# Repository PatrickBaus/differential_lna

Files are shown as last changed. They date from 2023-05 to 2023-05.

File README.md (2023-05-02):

Low Noise Differential Amplifier
===================

This repository contains the schematics and mechanical files for a low noise diffrential amplifier based on the Linear Technologies [AN-159](https://www.analog.com/media/en/technical-documentation/app-notes/an-159.pdf).

Key Features:
 * Bandwidth (-3 dB): 10 Hz - 1.5 MHz
 * Gain: 80 dB (10.000)
 * Noise floor $500\text{ pV}/\sqrt{\text{Hz}}$
 * Note: Requires a very low source impedance! Less than 10 Ohm.

The design was done using [KiCAD 7](https://www.kicad.org/).

Mechanical Design
------------------------------
The PCB should be housed in a mild steel box (e.g. cookie jar).

About
-----

The root folder contains the KiCAD files, while the gerber files can be found in the [/gerber](gerber/) folder, the bill of materials in the [/bom](bom/) folder.

Related Repositories
--------------------

See the following repositories for more information

KiCAD footprints: https://github.com/PatrickBaus/footprints.pretty

KiCAD 3D models: https://github.com/PatrickBaus/footprints.3dshapes

KiCAD schematic libraries: https://github.com/PatrickBaus/KiCad-libraries

License
-------

This work is released under the Cern OHL v.1.2
See www.ohwr.org/licenses/cern-ohl/v1.2 or the included LICENSE file for more information.

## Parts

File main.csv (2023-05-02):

Source: | /home/maat/Documents/Uni/Physik/Phd/Low Noise Amp/KiCAD/main.sch
Date: | 2017-03-31T00:32:30 CEST
Tool: | Eeschema (2017-01-18 revision 2eb840b2e)-master
Component Count: | 177
Ref | Qnty | Value | Cmp name | Footprint | Description | Vendor
C1, C27, C67, C72, C77, | 5 | 1u | FCA1206A105M-H3 | Capacitors_SMD:C_1206 | Unpolarized capacitor | Cornell Dubilier | 15 | x
C2, C3, C68, C69, C73, C74, C78, C79, | 8 | 33p | 12065A330JAT2A | Capacitors_SMD:C_1206 | Unpolarized capacitor | AVX | 20 | x
C4, C5, C28, C29, C30, C31, C36, C37, C70, C71, C75, C76, C80, C81, | 14 | 1u | MKS2C041001F00KC00 | Capacitors_ThroughHole:C_Rect_L7.2mm_W5.5mm_P5.00mm_FKS2_FKP2_MKS2_MKP2 | Unpolarized capacitor | WIMA | 30 | x
C6, C8, C10, C12, C14, C16, C18, C20, C22, C24, C7, C9, C11, C13, C15, C17, C19, C21, C23, C25, | 20 | 150u | T491X157K020AT | Capacitors_Tantalum_SMD:CP_Tantalum_Case-X_EIA-7343-43_Reflow | Polarised capacitor | Kemet | 50 | x
C26, | 1 | 2.2n | FKP2D012201D00JSSD | Capacitors_ThroughHole:C_Rect_L7.2mm_W4.5mm_P5.00mm_FKS2_FKP2_MKS2_MKP2 | Unpolarized capacitor | WIMA
C32, C33, | 2 | 330u | TPSE337M010R0100 | Capacitors_Tantalum_SMD:CP_Tantalum_Case-D_EIA-7343-31_Reflow | Polarised capacitor | AVX | 5 | x
C34, C35, | 2 | 4.7u | MKS2B044701K00KC00 | Capacitors_ThroughHole:C_Rect_L7.2mm_W8.5mm_P5.00mm_FKP2_FKP2_MKS2_MKP2 | Unpolarized capacitor | WIMA | 5 | x
C38, | 1 | 120p | 12065A121JAT2A | Capacitors_SMD:C_1206 | Unpolarized capacitor | AVX | 5 | x
C39, | 1 | 1.2n | 12065A122JAT2A | Capacitors_SMD:C_1206 | Unpolarized capacitor | AVX | 5 | x
C40, | 1 | 100p | 12065A101JAT2A | Capacitors_SMD:C_1206 | Unpolarized capacitor | AVX | 5 | x
C41, | 1 | 1n | 12065A102JAT2A | Capacitors_SMD:C_1206 | Unpolarized capacitor | AVX | 5 | x
C42, | 1 | 150p | 12065A151JAT2A | Capacitors_SMD:C_1206 | Unpolarized capacitor | AVX | 5 | x
C43, | 1 | 1.5n | 12065A152JAT2A | Capacitors_SMD:C_1206 | Unpolarized capacitor | AVX | 5 | x
C44, | 1 | 22p | 12065A220JAT2A | Capacitors_SMD:C_1206 | Unpolarized capacitor | AVX | 5 | x
C45, | 1 | 220p | 12065A221JAT2A | Capacitors_SMD:C_1206 | Unpolarized capacitor | AVX | 5 | x
C57, C64, C58, C65, C59, C66, C52, C48, C51, C47, C50, C46, C63, C55, C62, C54, C61, C53, C60, C56, C49, | 21 | 100u | GRM32ER61A107ME20K | Capacitors_SMD:C_1210 | Unpolarized capacitor | Murata | 50 | x
C82, | 2 | 180u | 25SEPF180M | Capacitors_ThroughHole:CP_Radial_D8.0mm_P3.50mm | Polarised capacitor | Panasonic | 5 | x
FID1, FID2, FID3, | 3 | FIDUCIAL |  | Fiducials:Fiducial_1mm_Dia_2.54mm_Outer_CopperTop | Fiducial for pick and place maschines
J3, J4, J5, J6, | 4 | CONN_01X01 |  | Wire_Pads:SolderWirePad_single_2-5mmDrill | Connector, single row, 01x01, pin header
P2, P1, P3, J1, J2, | 5 | SMA |  | Connect:SMA_THT_Jack_Straight
Q1, Q2, Q3, Q4, | 4 | THAT300 |  | Housings_SOIC:SOIC-14_3.9x8.7mm_Pitch1.27mm | NPN Array |  | 8 | x
R1, R2, R45, R46, R47, R48, R59, R60, | 8 | 100 | MFR-25FBF52-100R | Resistors_ThroughHole:R_Axial_DIN0207_L6.3mm_D2.5mm_P10.16mm_Horizontal | Resistor | Yageo | 20 | x
R3, R4, R35, R36, R49, R50, R61, R62, | 8 | 49.9 | MFR-25FBF52-49R9 | Resistors_ThroughHole:R_Axial_DIN0207_L6.3mm_D2.5mm_P10.16mm_Horizontal | Resistor | Yageo | 20 | x
R5, R7, R6, R10, R37, R39, R38, R42, R51, R53, R52, R56, R63, R65, R64, R68, | 16 | 4.02k | MFR-25FBF52-4K02 | Resistors_ThroughHole:R_Axial_DIN0207_L6.3mm_D2.5mm_P10.16mm_Horizontal | Resistor | Yageo | 35 | x
R9, R8, R41, R40, R55, R54, R67, R66, | 8 | 1.3k | MFR-25FRF52-1K3 | Resistors_ThroughHole:R_Axial_DIN0207_L6.3mm_D2.5mm_P10.16mm_Horizontal | Resistor | Yageo | 20 | x
R11, R12, R43, R44, R57, R58, R69, R70, | 8 | 1k | CPF0805B1K0E | Resistors_SMD:R_0805 | Resistor | TE Connectivity | 20 | x
R13, R18, R19, | 3 | 1k | MFR-25FBF52-1K | Resistors_ThroughHole:R_Axial_DIN0207_L6.3mm_D2.5mm_P10.16mm_Horizontal | Resistor | Yageo | 5+3 | x
R14, R15, | 2 | 249 | SFR2500002490FR500 | Resistors_ThroughHole:R_Axial_DIN0207_L6.3mm_D2.5mm_P10.16mm_Horizontal | Resistor | Vishay | 5 | x
R16, R17, | 2 | 475 | MFR-25FRF52-475R | Resistors_ThroughHole:R_Axial_DIN0207_L6.3mm_D2.5mm_P10.16mm_Horizontal | Resistor | Yageo | 5 | x
R20, | 1 | 1.13k | CRCW12061K13FKEA | Resistors_SMD:R_1206 | Resistor | Vishay | 10 | x
R21, | 1 | 10.2k | CRCW120610K2FKEA | Resistors_SMD:R_1206 | Resistor | Vishay | 10 | x
R22, | 1 | 100 | CRCW1206100RFKEA | Resistors_SMD:R_1206 | Resistor | Vishay | 5 | x
R23, | 1 | 1.5k | CRCW12061K50FKEA | Resistors_SMD:R_1206 | Resistor | Vishay | 5 | x
R24, R25, | 2 | 1.69k | CRCW12061K69FKEA | Resistors_SMD:R_1206 | Resistor | Vishay | 5 | x
R26, R27, | 2 | 1.24k | CRCW12061K24FKEA | Resistors_SMD:R_1206 | Resistor | Vishay | 5 | x
R28, R29, | 2 | 4.02k | CRCW12064K02FKEA | Resistors_SMD:R_1206 | Resistor | Vishay | 5 | x
R30, R31, | 2 | 2.15k | CRCW12062K15FKEA | Resistors_SMD:R_1206 | Resistor | Vishay | 5 | x
R33, R32, R34, | 3 | 49.9 | CRCW120649R9FKEA | Resistors_SMD:R_1206 | Resistor | Vishay | 10 | x
RV1, | 1 | 1k | 3296Y-1-102 | Potentiometers:Potentiometer_Trimmer_Bourns_3296Y | Potentionmeter | Bourns | 3 | x
U1, U2, U5, U6, U7, | 5 | LT1994 |  | Housings_SSOP:MSOP-8_3x3mm_Pitch0.65mm | Low Noise, Low Distortion Fully Differential Input/Output Amplifier/Driver |  | 12 | x
U3, | 1 | LT6232 |  | Housings_SSOP:SSOP-16_3.9x4.9mm_Pitch0.635mm | 215MHz, Rail-to-Rail Output, 1.1nV/√Hz, 3.5mA Op Amp |  | 3 | x
U4, | 1 | LT1365 |  | Housings_SOIC:SOIC-16_3.9x9.9mm_Pitch1.27mm |  |  | 2 | x

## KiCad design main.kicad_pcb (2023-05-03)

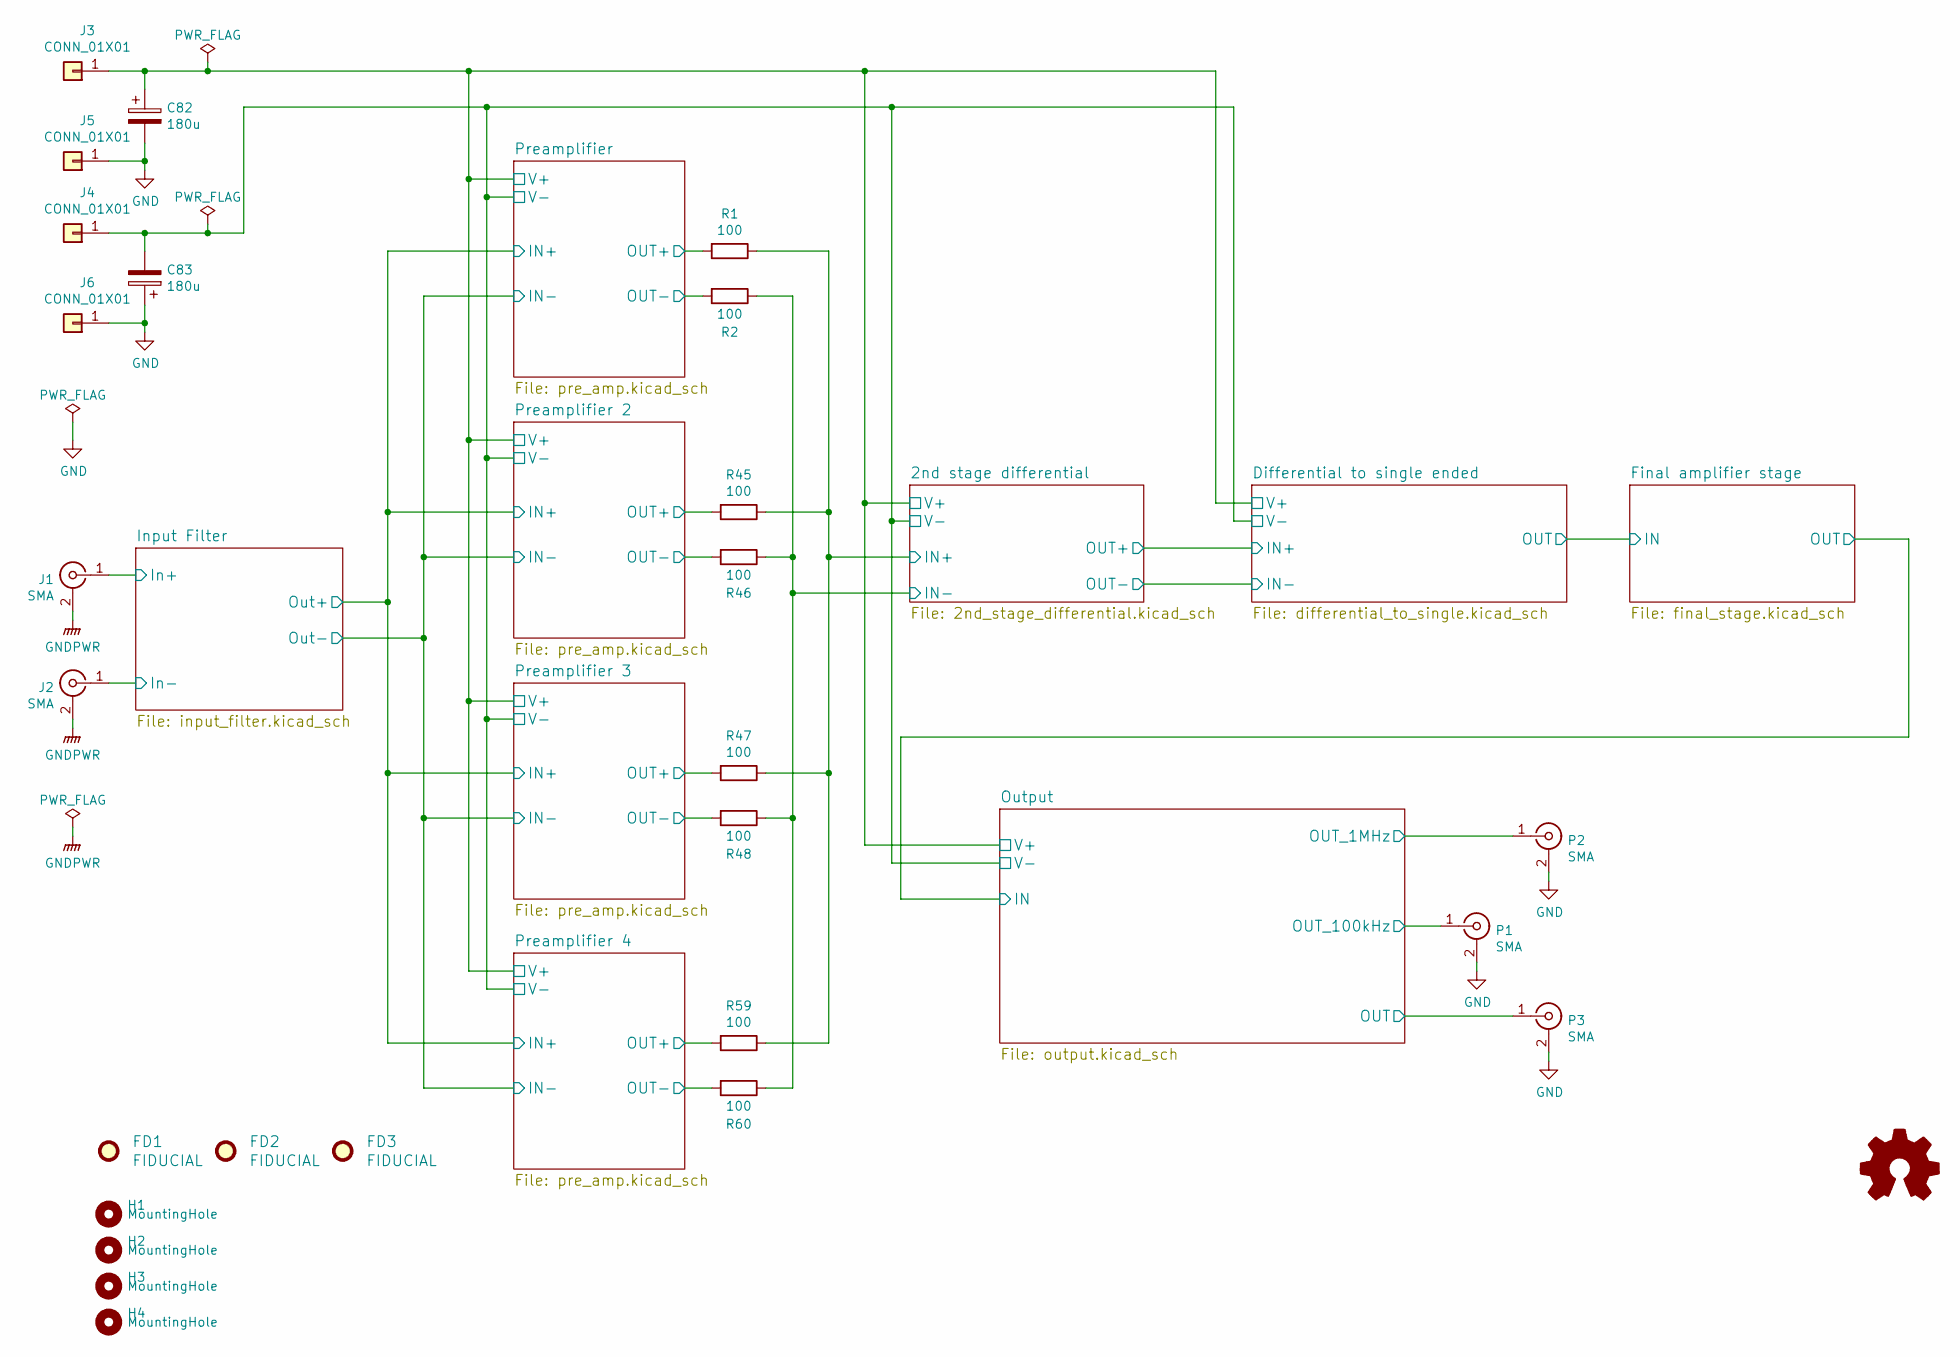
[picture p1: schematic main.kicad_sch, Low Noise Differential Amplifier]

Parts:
C82, C83: 180u; CP_Radial_D8.0mm_P3.50mm
FD1, FD2, FD3: FIDUCIAL; Fiducial_1mm_Mask2mm
H1, H2, H3, H4: MountingHole; MountingHole_3.2mm_M3_DIN965
J1, J2: SMA; SMA_Amphenol_901-144_Vertical
J3, J4, J5, J6: CONN_01X01; TestPoint_Loop_D3.80mm_Drill2.5mm
P1, P2, P3: SMA; SMA_Amphenol_901-144_Vertical
R1, R2, R45, R46, R47, R48, R59, R60: 100; R_Axial_DIN0207_L6.3mm_D2.5mm_P10.16mm_Horizontal

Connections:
/2nd stage differential/IN+: R1.1, R45.1, R47.1, R59.1; also elsewhere on the board
/2nd stage differential/IN-: R2.1, R46.1, R48.1, R60.1; also elsewhere on the board
/2nd stage differential/V+: C82.1, J3.1; also elsewhere on the board
/2nd stage differential/V-: C83.2, J4.1; also elsewhere on the board
/Input Filter/In+: J1.1 (In); also elsewhere on the board
/Input Filter/In-: J2.1 (In); also elsewhere on the board
/Output/OUT: P3.1 (In); also elsewhere on the board
/Output/OUT_1MHz: P2.1 (In); also elsewhere on the board
/Output/OUT_100kHz: P1.1 (In); also elsewhere on the board
/Preamplifier 2/OUT+: R45.2; also elsewhere on the board
/Preamplifier 2/OUT-: R46.2; also elsewhere on the board
/Preamplifier 3/OUT+: R47.2; also elsewhere on the board
/Preamplifier 3/OUT-: R48.2; also elsewhere on the board
/Preamplifier 4/OUT+: R59.2; also elsewhere on the board
/Preamplifier 4/OUT-: R60.2; also elsewhere on the board
/Preamplifier/OUT+: R1.2; also elsewhere on the board
/Preamplifier/OUT-: R2.2; also elsewhere on the board
GND: C82.2, C83.1, J5.1, J6.1, P1.2 (Ext), P2.2 (Ext), P3.2 (Ext); also elsewhere on the board
GNDPWR: J1.2 (Ext), J2.2 (Ext)

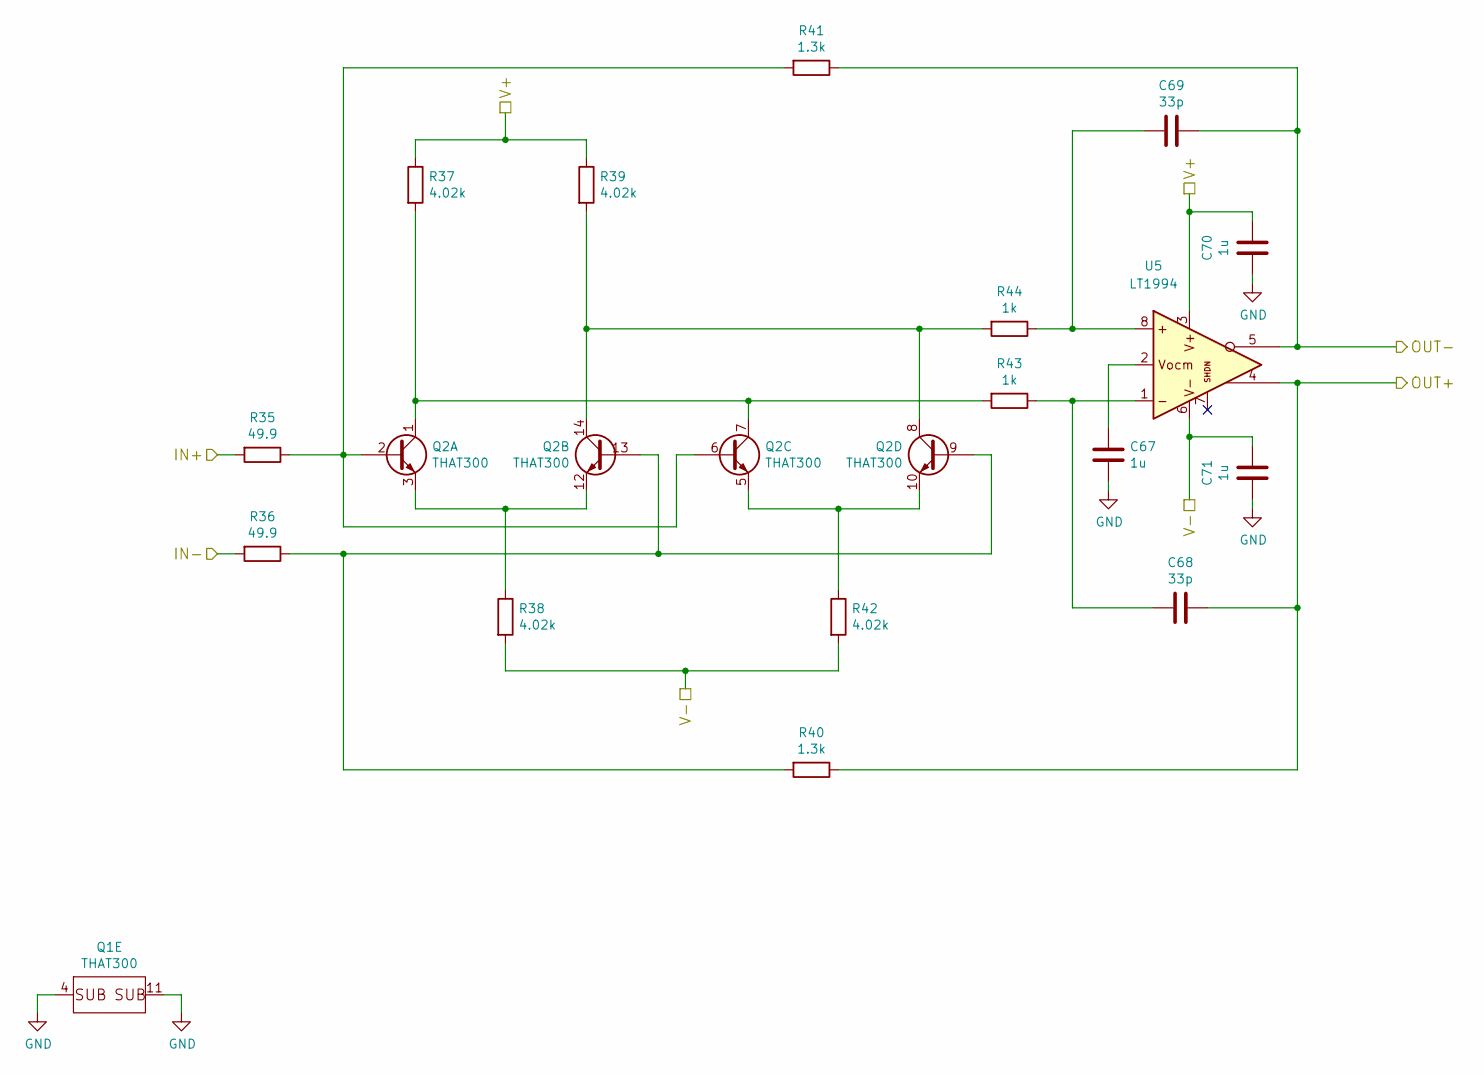
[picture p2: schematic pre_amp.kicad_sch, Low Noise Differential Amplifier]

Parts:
C67: 1u; C_1206_3216Metric
C68, C69: 33p; C_1206_3216Metric
C70, C71: 1u; C_Rect_L7.2mm_W5.5mm_P5.00mm_FKS2_FKP2_MKS2_MKP2
Q1, Q2: THAT300; SOIC-14_3.9x8.7mm_P1.27mm
R35, R36: 49.9; R_Axial_DIN0207_L6.3mm_D2.5mm_P10.16mm_Horizontal
R37, R38, R39, R42: 4.02k; R_Axial_DIN0207_L6.3mm_D2.5mm_P10.16mm_Horizontal
R40, R41: 1.3k; R_Axial_DIN0207_L6.3mm_D2.5mm_P10.16mm_Horizontal
R43, R44: 1k; R_0805_2012Metric
U5: LT1994; MSOP-8_3x3mm_P0.65mm

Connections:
/2nd stage differential/V+: C70.1, R37.1, R39.1, U5.3; also elsewhere on the board
/2nd stage differential/V-: C71.1, R38.2, R42.2, U5.6; also elsewhere on the board
/Input Filter/Out+: R35.2; also elsewhere on the board
/Input Filter/Out-: R36.2; also elsewhere on the board
/Preamplifier 2/OUT+: C68.1, R40.1, U5.4; also elsewhere on the board
/Preamplifier 2/OUT-: C69.1, R41.1, U5.5; also elsewhere on the board
GND: C67.2, C70.2, C71.2, Q1.4 (B), Q1.11 (E), Q2.4 (B), Q2.11 (E); also elsewhere on the board
unnamed: C67.1, U5.2
unnamed: C68.2, R43.1, U5.1
unnamed: C69.2, R44.1, U5.8
unnamed 46: Q1.2 (B), Q1.6 (B); also elsewhere on the board
unnamed 47: Q1.1 (C), Q1.7 (C); also elsewhere on the board
unnamed 48: Q1.3 (E), Q1.12 (E); also elsewhere on the board
unnamed 49: Q1.9 (B), Q1.13 (B); also elsewhere on the board
unnamed 50: Q1.8, Q1.14 (C); also elsewhere on the board
unnamed 51: Q1.5 (E), Q1.10 (E); also elsewhere on the board
unnamed: Q2.2 (B), Q2.6 (B), R35.1, R41.2
unnamed: Q2.1 (C), Q2.7 (C), R37.2, R43.2
unnamed: Q2.3 (E), Q2.12 (E), R38.1
unnamed: Q2.9 (B), Q2.13 (B), R36.1, R40.2
unnamed: Q2.8, Q2.14 (C), R39.2, R44.2
unnamed: Q2.5 (E), Q2.10 (E), R42.1

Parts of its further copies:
C1, C72, C77: 1u; C_1206_3216Metric
C2, C3, C73, C74, C78, C79: 33p; C_1206_3216Metric
C4, C5, C75, C76, C80, C81: 1u; C_Rect_L7.2mm_W5.5mm_P5.00mm_FKS2_FKP2_MKS2_MKP2
Q3, Q4: THAT300; SOIC-14_3.9x8.7mm_P1.27mm
R3, R4, R49, R50, R61, R62: 49.9; R_Axial_DIN0207_L6.3mm_D2.5mm_P10.16mm_Horizontal
R5, R6, R7, R10, R51, R52, R53, R56, R63, R64, R65, R68: 4.02k; R_Axial_DIN0207_L6.3mm_D2.5mm_P10.16mm_Horizontal
R8, R9, R54, R55, R66, R67: 1.3k; R_Axial_DIN0207_L6.3mm_D2.5mm_P10.16mm_Horizontal
R11, R12, R57, R58, R69, R70: 1k; R_0805_2012Metric
U1, U6, U7: LT1994; MSOP-8_3x3mm_P0.65mm

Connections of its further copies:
/2nd stage differential/V+: C4.1, C75.1, C80.1, R5.1, R7.1, R51.1, R53.1, R63.1, R65.1, U1.3, U6.3, U7.3; also elsewhere on the board
/2nd stage differential/V-: C5.1, C76.1, C81.1, R6.2, R10.2, R52.2, R56.2, R64.2, R68.2, U1.6, U6.6, U7.6; also elsewhere on the board
/Input Filter/Out+: R3.2, R49.2, R61.2; also elsewhere on the board
/Input Filter/Out-: R4.2, R50.2, R62.2; also elsewhere on the board
/Preamplifier 3/OUT+: C73.1, R54.1, U6.4; also elsewhere on the board
/Preamplifier 3/OUT-: C74.1, R55.1, U6.5; also elsewhere on the board
/Preamplifier 4/OUT+: C78.1, R66.1, U7.4; also elsewhere on the board
/Preamplifier 4/OUT-: C79.1, R67.1, U7.5; also elsewhere on the board
/Preamplifier/OUT+: C2.1, R8.1, U1.4; also elsewhere on the board
/Preamplifier/OUT-: C3.1, R9.1, U1.5; also elsewhere on the board
GND: C1.2, C4.2, C5.2, C72.2, C75.2, C76.2, C77.2, C80.2, C81.2, Q3.4 (B), Q3.11 (E), Q4.4 (B), Q4.11 (E); also elsewhere on the board
unnamed: C1.1, U1.2
unnamed: C2.2, R11.1, U1.1
unnamed: C3.2, R12.1, U1.8
unnamed: C72.1, U6.2
unnamed: C73.2, R57.1, U6.1
unnamed: C74.2, R58.1, U6.8
unnamed: C77.1, U7.2
unnamed: C78.2, R69.1, U7.1
unnamed: C79.2, R70.1, U7.8
unnamed 46: R3.1, R9.2; also elsewhere on the board
unnamed 47: R5.2, R11.2; also elsewhere on the board
unnamed 48: R6.1; also elsewhere on the board
unnamed 49: R4.1, R8.2; also elsewhere on the board
unnamed 50: R7.2, R12.2; also elsewhere on the board
unnamed 51: R10.1; also elsewhere on the board
unnamed: Q3.2 (B), Q3.6 (B), R49.1, R55.2
unnamed: Q3.1 (C), Q3.7 (C), R51.2, R57.2
unnamed: Q3.3 (E), Q3.12 (E), R52.1
unnamed: Q3.9 (B), Q3.13 (B), R50.1, R54.2
unnamed: Q3.8, Q3.14 (C), R53.2, R58.2
unnamed: Q3.5 (E), Q3.10 (E), R56.1
unnamed: Q4.2 (B), Q4.6 (B), R61.1, R67.2
unnamed: Q4.1 (C), Q4.7 (C), R63.2, R69.2
unnamed: Q4.3 (E), Q4.12 (E), R64.1
unnamed: Q4.9 (B), Q4.13 (B), R62.1, R66.2
unnamed: Q4.8, Q4.14 (C), R65.2, R70.2
unnamed: Q4.5 (E), Q4.10 (E), R68.1

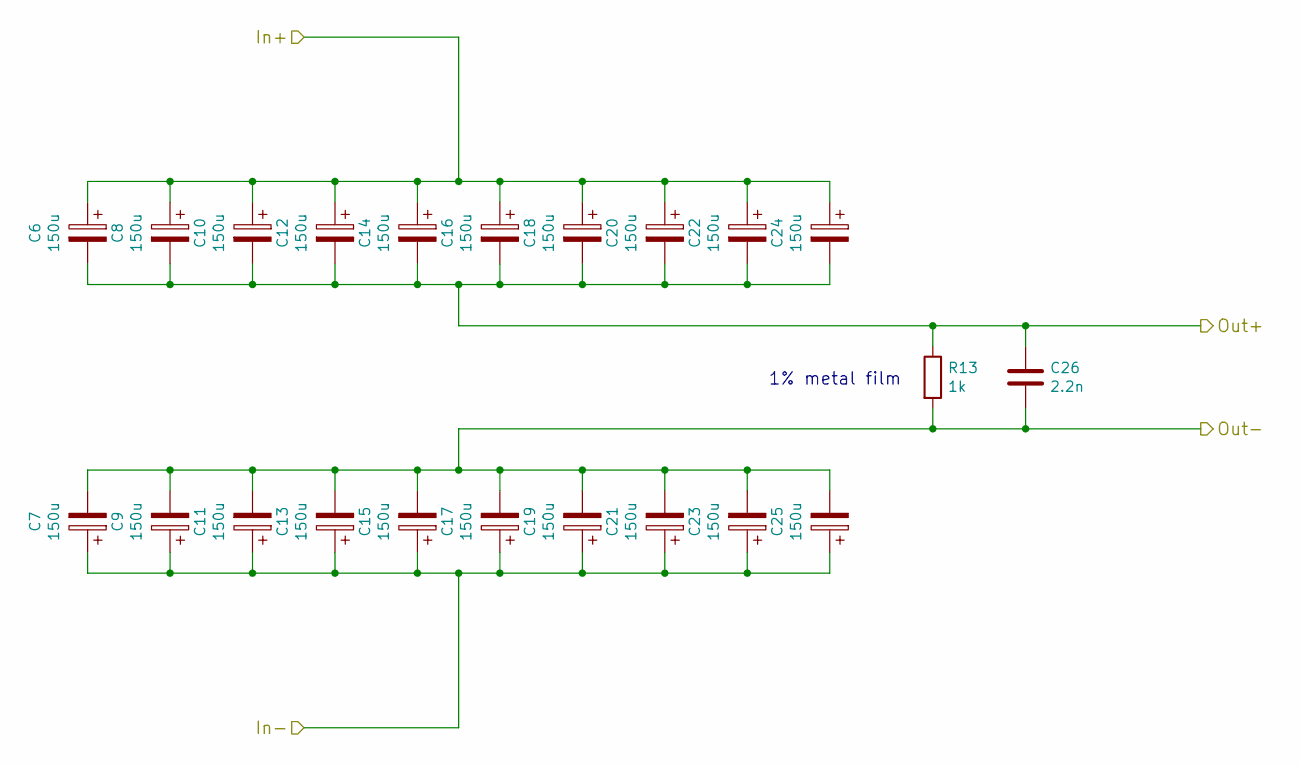
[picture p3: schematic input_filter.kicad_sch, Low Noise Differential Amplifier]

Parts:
C6, C7, C8, C9, C10, C11, C12, C13, C14, C15, C16, C17, C18, C19, C20, C21, C22, C23, C24, C25: 150u; CP_EIA-7343-43_Kemet-X
C26: 2.2n; C_Rect_L7.2mm_W4.5mm_P5.00mm_FKS2_FKP2_MKS2_MKP2
R13: 1k; R_Axial_DIN0207_L6.3mm_D2.5mm_P10.16mm_Horizontal

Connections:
/Input Filter/In+: C6.1, C8.1, C10.1, C12.1, C14.1, C16.1, C18.1, C20.1, C22.1, C24.1; also elsewhere on the board
/Input Filter/In-: C7.1, C9.1, C11.1, C13.1, C15.1, C17.1, C19.1, C21.1, C23.1, C25.1; also elsewhere on the board
/Input Filter/Out+: C6.2, C8.2, C10.2, C12.2, C14.2, C16.2, C18.2, C20.2, C22.2, C24.2, C26.1, R13.1; also elsewhere on the board
/Input Filter/Out-: C7.2, C9.2, C11.2, C13.2, C15.2, C17.2, C19.2, C21.2, C23.2, C25.2, C26.2, R13.2; also elsewhere on the board

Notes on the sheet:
1% metal film

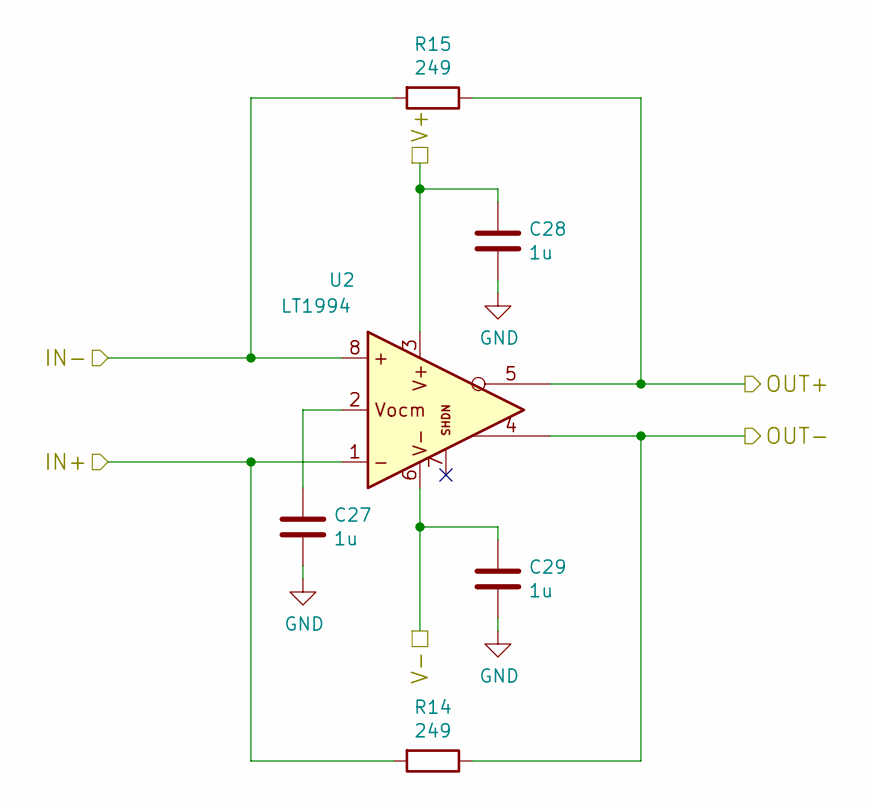
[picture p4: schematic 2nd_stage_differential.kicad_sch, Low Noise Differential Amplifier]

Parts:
C27: 1u; C_1206_3216Metric
C28, C29: 1u; C_Rect_L7.2mm_W5.5mm_P5.00mm_FKS2_FKP2_MKS2_MKP2
R14, R15: 249; R_Axial_DIN0207_L6.3mm_D2.5mm_P10.16mm_Horizontal
U2: LT1994; MSOP-8_3x3mm_P0.65mm

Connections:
/2nd stage differential/IN+: R14.2, U2.1; also elsewhere on the board
/2nd stage differential/IN-: R15.2, U2.8; also elsewhere on the board
/2nd stage differential/OUT+: R15.1, U2.5; also elsewhere on the board
/2nd stage differential/OUT-: R14.1, U2.4; also elsewhere on the board
/2nd stage differential/V+: C28.1, U2.3; also elsewhere on the board
/2nd stage differential/V-: C29.1, U2.6; also elsewhere on the board
GND: C27.2, C28.2, C29.2; also elsewhere on the board
unnamed: C27.1, U2.2

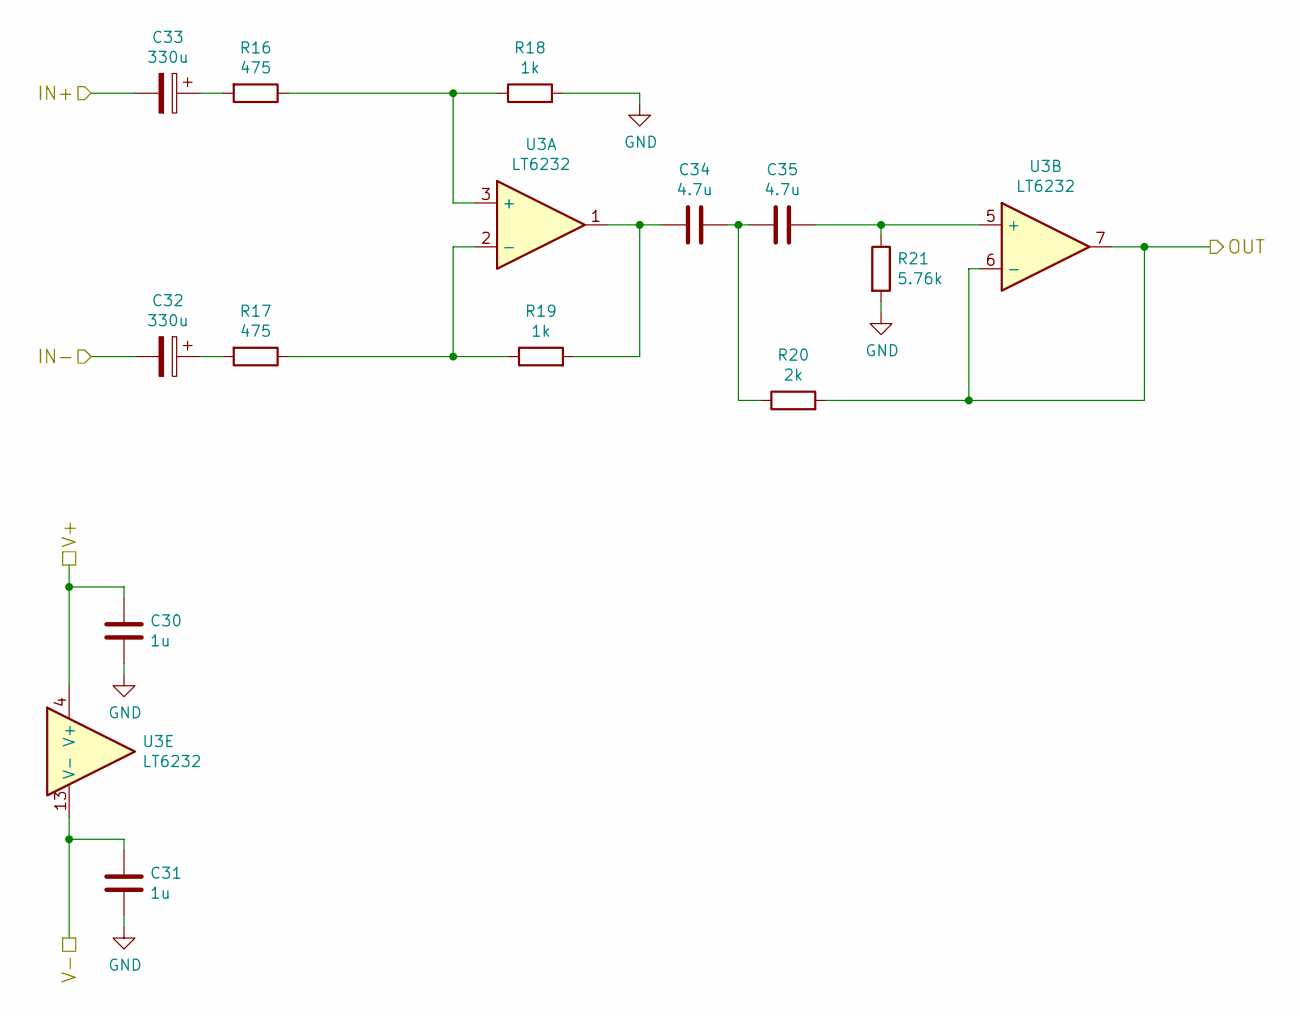
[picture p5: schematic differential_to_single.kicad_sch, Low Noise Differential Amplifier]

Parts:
C30, C31: 1u; C_Rect_L7.2mm_W5.5mm_P5.00mm_FKS2_FKP2_MKS2_MKP2
C32, C33: 330u; CP_EIA-7343-31_Kemet-D
C34, C35: 4.7u; C_Rect_L7.2mm_W8.5mm_P5.00mm_FKP2_FKP2_MKS2_MKP2
R16, R17: 475; R_Axial_DIN0207_L6.3mm_D2.5mm_P10.16mm_Horizontal
R18, R19: 1k; R_Axial_DIN0207_L6.3mm_D2.5mm_P10.16mm_Horizontal
R20: 2k; R_1206_3216Metric
R21: 5.76k; R_1206_3216Metric
U3: LT6232; SSOP-16_3.9x4.9mm_P0.635mm

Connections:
/2nd stage differential/OUT+: C33.2; also elsewhere on the board
/2nd stage differential/OUT-: C32.2; also elsewhere on the board
/2nd stage differential/V+: C30.1, U3.4 (V+); also elsewhere on the board
/2nd stage differential/V-: C31.1, U3.13 (V-); also elsewhere on the board
/Differential to single ended/OUT: R20.2, U3.6 (-), U3.7; also elsewhere on the board
GND: C30.2, C31.2, R18.2, R21.2; also elsewhere on the board
unnamed: C32.1, R17.2
unnamed: C33.1, R16.2
unnamed: C34.1, C35.2, R20.1
unnamed: C34.2, R19.2, U3.1
unnamed: R16.1, R18.1, U3.3 (+)
unnamed: R17.1, R19.1, U3.2 (-)
unnamed: C35.1, R21.1, U3.5 (+)

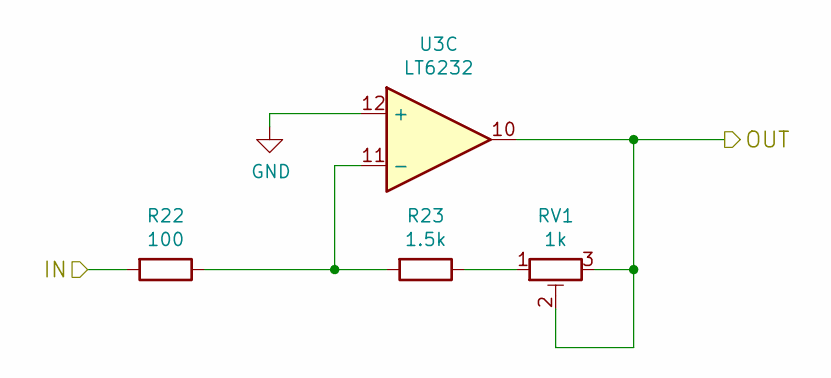
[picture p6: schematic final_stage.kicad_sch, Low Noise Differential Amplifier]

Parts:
R22: 100; R_1206_3216Metric
R23: 1.5k; R_1206_3216Metric
RV1: 1k; Potentiometer_Bourns_3296Y_Vertical
U3: LT6232; SSOP-16_3.9x4.9mm_P0.635mm

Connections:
/Differential to single ended/OUT: R22.2; also elsewhere on the board
/Final amplifier stage/OUT: RV1.2, RV1.3, U3.10; also elsewhere on the board
GND: U3.12 (+); also elsewhere on the board
unnamed: R23.1, RV1.1
unnamed: R22.1, R23.2, U3.11 (-)

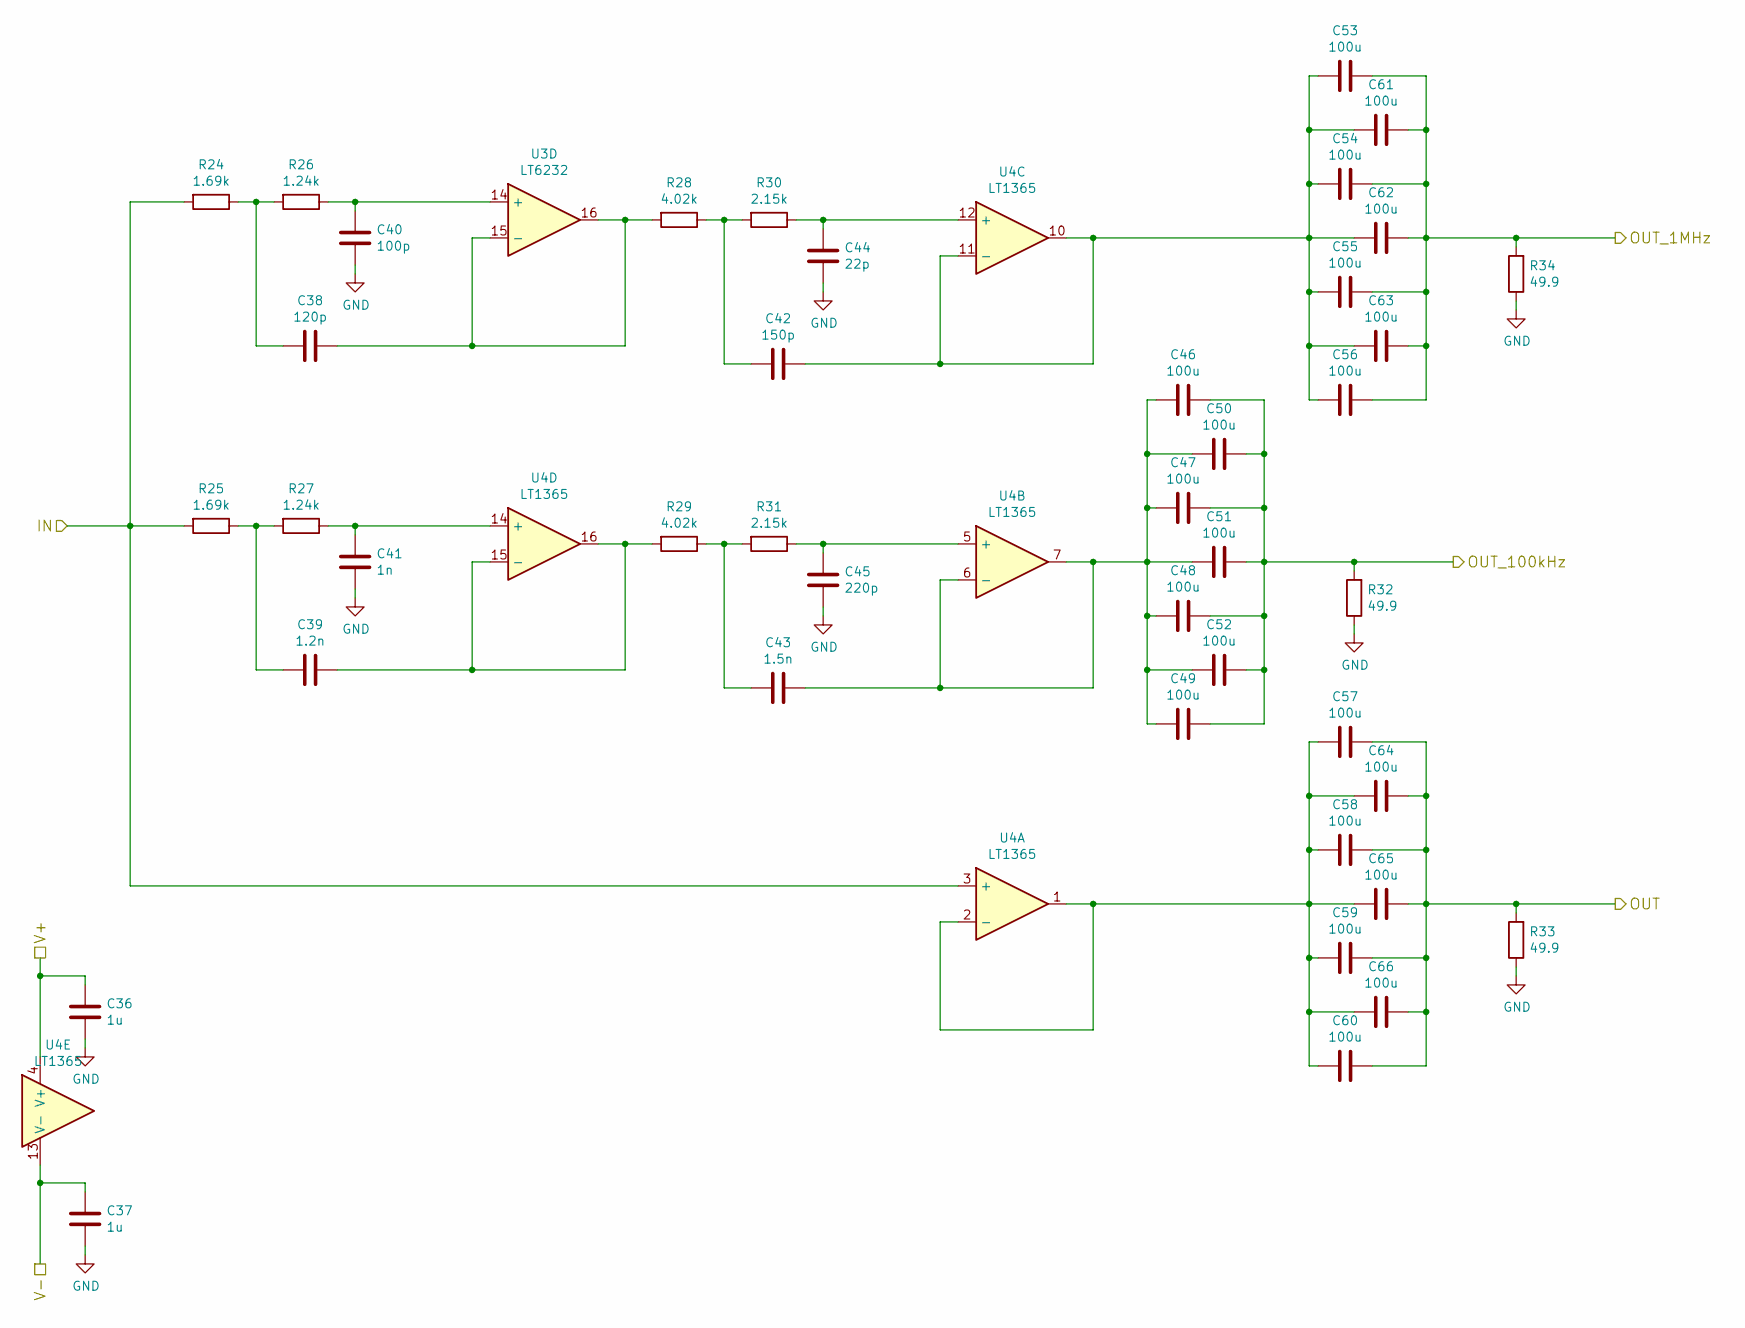
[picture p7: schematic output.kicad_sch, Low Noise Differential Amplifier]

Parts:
C36, C37: 1u; C_Rect_L7.2mm_W5.5mm_P5.00mm_FKS2_FKP2_MKS2_MKP2
C38: 120p; C_1206_3216Metric
C39: 1.2n; C_1206_3216Metric
C40: 100p; C_1206_3216Metric
C41: 1n; C_1206_3216Metric
C42: 150p; C_1206_3216Metric
C43: 1.5n; C_1206_3216Metric
C44: 22p; C_1206_3216Metric
C45: 220p; C_1206_3216Metric
C46, C47, C48, C49, C50, C51, C52, C53, C54, C55, C56, C57, C58, C59, C60, C61, C62, C63, C64, C65, C66: 100u; C_1210_3225Metric
R24, R25: 1.69k; R_1206_3216Metric
R26, R27: 1.24k; R_1206_3216Metric
R28, R29: 4.02k; R_1206_3216Metric
R30, R31: 2.15k; R_1206_3216Metric
R32, R33, R34: 49.9; R_1206_3216Metric
U3: LT6232; SSOP-16_3.9x4.9mm_P0.635mm
U4: LT1365; SOIC-16_3.9x9.9mm_P1.27mm

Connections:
/2nd stage differential/V+: C36.1, U4.4 (V+); also elsewhere on the board
/2nd stage differential/V-: C37.1, U4.13 (V-); also elsewhere on the board
/Final amplifier stage/OUT: R24.2, R25.2, U4.3 (+); also elsewhere on the board
/Output/OUT: C57.1, C58.1, C59.1, C60.1, C64.1, C65.1, C66.1, R33.2; also elsewhere on the board
/Output/OUT_1MHz: C53.1, C54.1, C55.1, C56.1, C61.1, C62.1, C63.1, R34.2; also elsewhere on the board
/Output/OUT_100kHz: C46.1, C47.1, C48.1, C49.1, C50.1, C51.1, C52.1, R32.2; also elsewhere on the board
GND: C36.2, C37.2, C40.2, C41.2, C44.2, C45.2, R32.1, R33.1, R34.1; also elsewhere on the board
unnamed: C38.2, R24.1, R26.2
unnamed: C39.2, R25.1, R27.2
unnamed: C42.2, R28.1, R30.2
unnamed: C43.2, R29.1, R31.2
unnamed: C40.1, R26.1, U3.14 (+)
unnamed: C38.1, R28.2, U3.15 (-), U3.16
unnamed: C57.2, C58.2, C59.2, C60.2, C64.2, C65.2, C66.2, U4.1, U4.2 (-)
unnamed: C45.1, R31.1, U4.5 (+)
unnamed: C43.1, C46.2, C47.2, C48.2, C49.2, C50.2, C51.2, C52.2, U4.6 (-), U4.7
unnamed: C44.1, R30.1, U4.12 (+)
unnamed: C42.1, C53.2, C54.2, C55.2, C56.2, C61.2, C62.2, C63.2, U4.10, U4.11 (-)
unnamed: C41.1, R27.1, U4.14 (+)
unnamed: C39.1, R29.2, U4.15 (-), U4.16

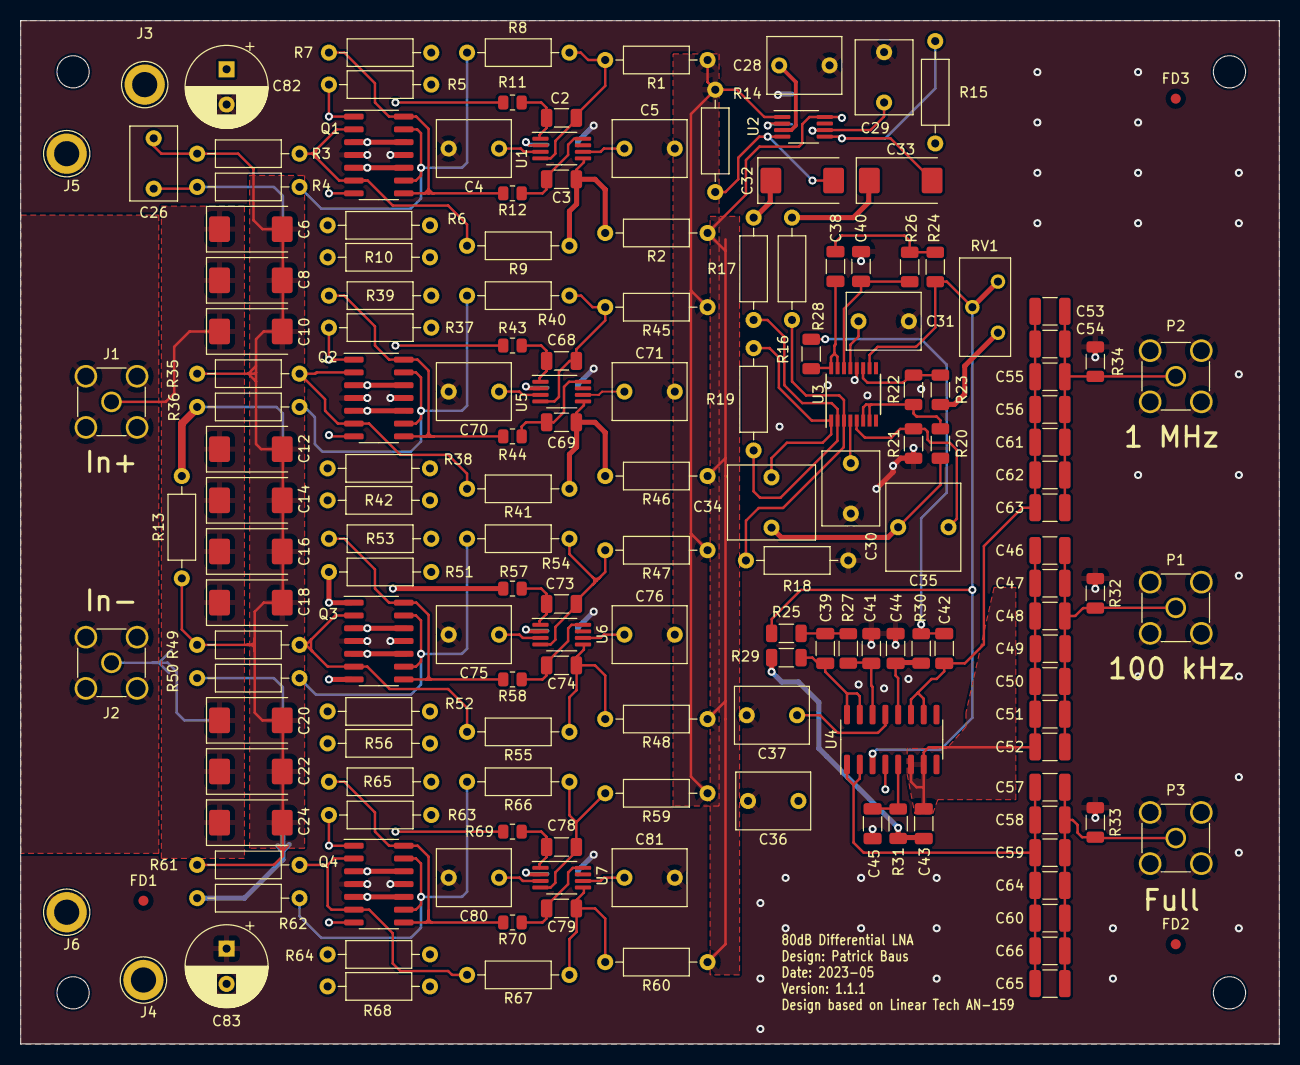
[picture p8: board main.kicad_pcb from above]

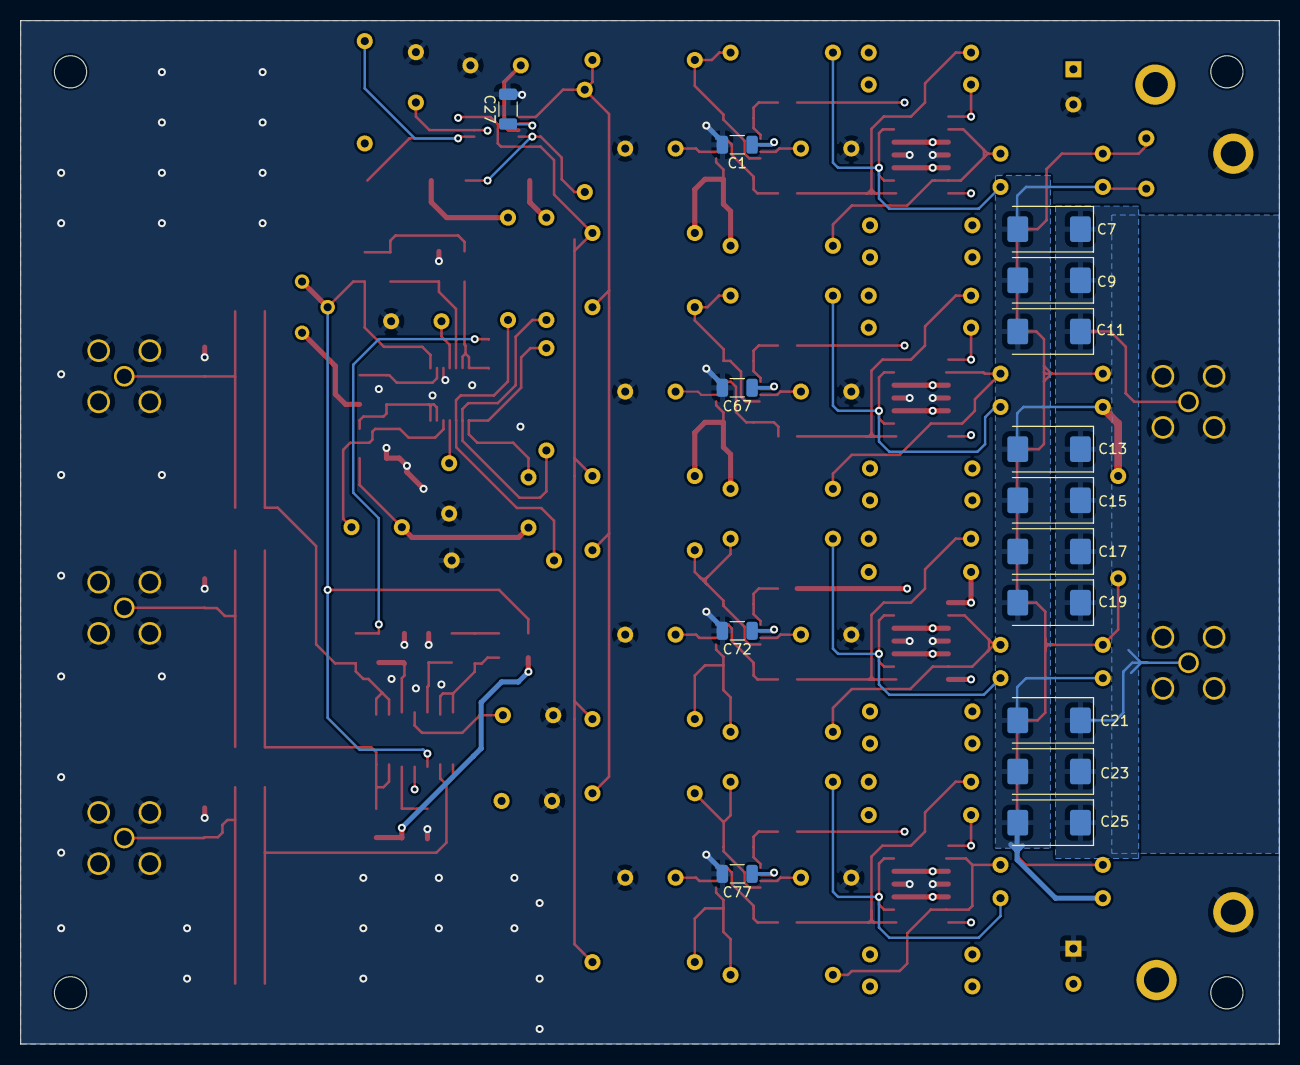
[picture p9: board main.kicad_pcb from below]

Board: 4 copper layers, 125.0 x 101.6 mm, 181 parts (15 on the bottom side), 84 nets.

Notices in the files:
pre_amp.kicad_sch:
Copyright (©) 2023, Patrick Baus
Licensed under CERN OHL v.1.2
